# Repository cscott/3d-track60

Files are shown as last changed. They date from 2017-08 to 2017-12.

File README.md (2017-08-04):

# Track for wooden trains (Brio, Lillabo, Thomas, etc) using 60° system

Thing tracker at:
https://cscott.github.io/thing-tracker/#/thing/4b2b1909-8ae7-4448-a28f-22e28d4b5b43

## Description

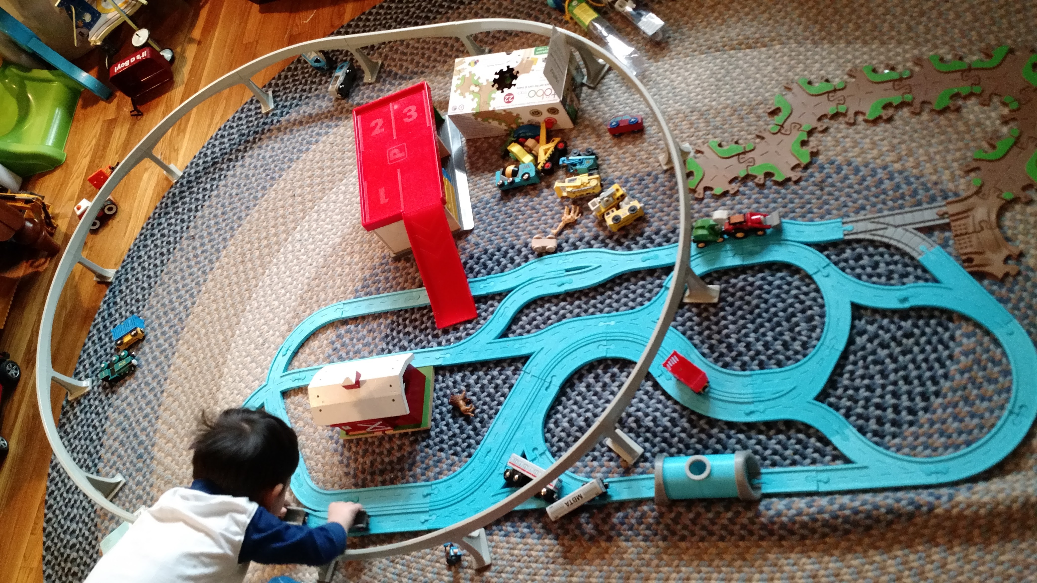
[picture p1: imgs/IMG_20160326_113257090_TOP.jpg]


These files contain a set of wooden-train-compatible track pieces in
the [sixty-degree system described by Dave
Barber](http://tamivox.org/dave/train/index60.html).  Unlike the
hodgepodge of pieces in the standard Brio/Thomas/Ikea/etc sets, track
assembled using these pieces will always go together and fit
perfectly.  No more frustration for you or your kids when your loops
don't *quite* close up.  No more [flexible
track](https://www.thingiverse.com/thing:661462) kludges.

In addition, I've made adapter pieces for many popular accessories,
such as those from the
[Ertl Hometown Roadway](http://magicref.tripod.com/trains/trainhistory2.htm),
so that they fit into the 60-degree system.

#### Some discussion of size

Dave Barber suggests a base radius for the system of 200mm.  The core
hexagon will then have a diameter of 267mm and straights will be 231mm
long.

I have instead chosen a base radius of 154mm, which makes 7 hex cells
arranged flat-to-flat measure 49 inches.  That works well with a
[wTrak]-like system with 48" tables and 1" gaps between them (filled
with leg assemblies).  Our straights are about 7" long.

For comparison, according to
[woodenrailway.info](http://www.woodenrailway.info/track/trackguide.html)
the standard Brio "E" curve has a centerline radius of 202mm
and the tighter Brio "E1" curve has a centerline radius of 110mm.
Typical Brio straights are 4.5", 5.5", and 8.5".  Our 154mm curves
and 7" straights fit reasonably well into this family.

For riser heights, although the Brio standard is 64mm, some other sets
have 62mm risers.  We've split the difference in making levels separated
by 63mm.  This should be easily interoperable with existing pieces using
either the 62mm or 64mm heights.

We like the ["clickity-clack track that Learning Curve abandoned years ago"](http://wtrak.org/tracks.htm) so our rail pieces contain grooves for the ties
in order to make that audible clack as trains are rolled over it.
Most of our pieces have road on one side and rail on the other, so you
can play with cars or trains or both.

<br clear="both" />

## Related

* Dave Barber's [Observations on Track for Toy Trains](http://tamivox.org/dave/train/)

## License

These designs are licensed under the [GPLv2+].

[wTrak]: http://wtrak.org/
[GPLv2+]: https://spdx.org/licenses/GPL-2.0+.html

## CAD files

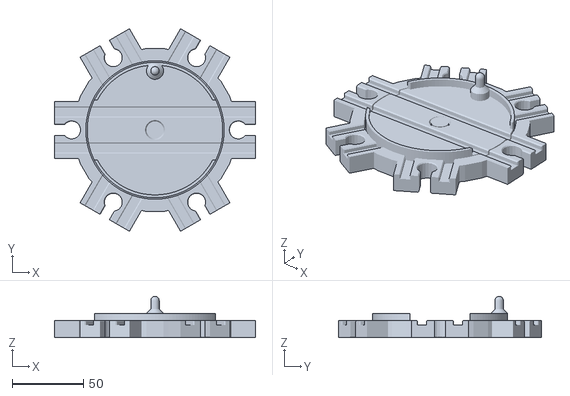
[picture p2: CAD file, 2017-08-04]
roundabout-stl/roundabout-6-assembled.stl
141.0 x 142.1 x 29.0

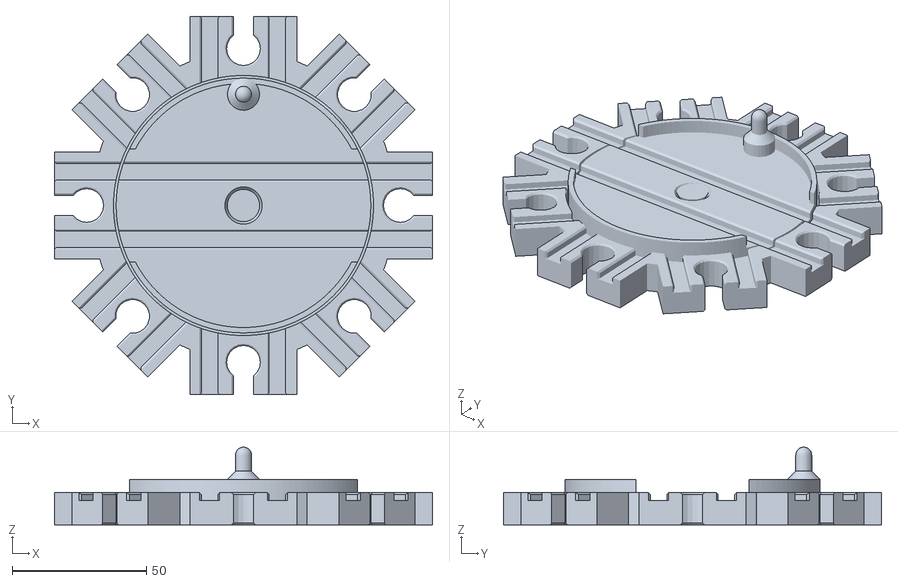
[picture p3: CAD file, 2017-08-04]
roundabout-stl/roundabout-8-assembled.stl
141.0 x 141.0 x 29.0

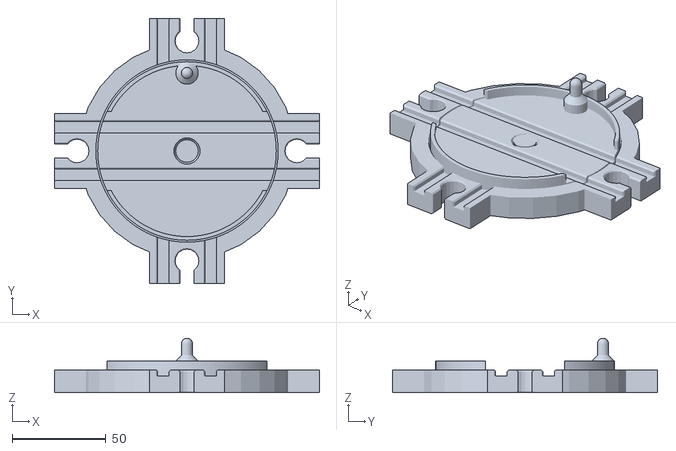
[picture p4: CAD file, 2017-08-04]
roundabout-stl/roundabout-4-assembled.stl
141.0 x 141.0 x 29.0

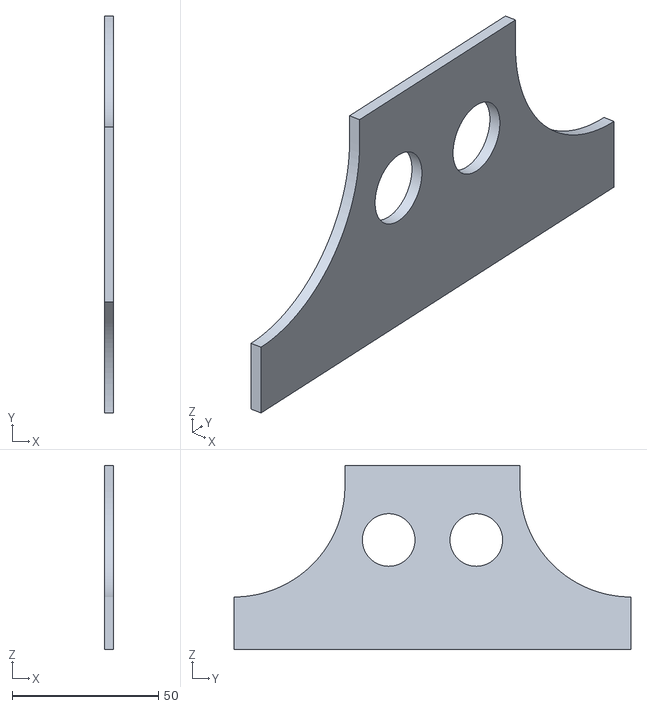
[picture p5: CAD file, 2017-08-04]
track60-boat-stl/track60-boat-side-left.stl
3.00 x 135.8 x 63.0

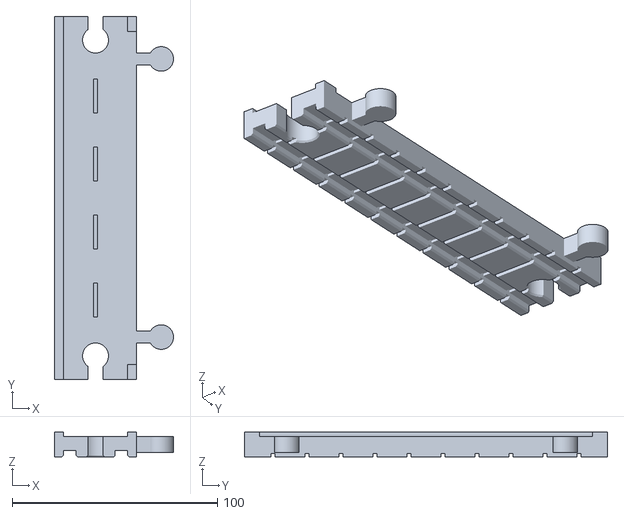
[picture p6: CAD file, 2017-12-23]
track60-stl/track60-pez.stl
58.0 x 176.8 x 12.0

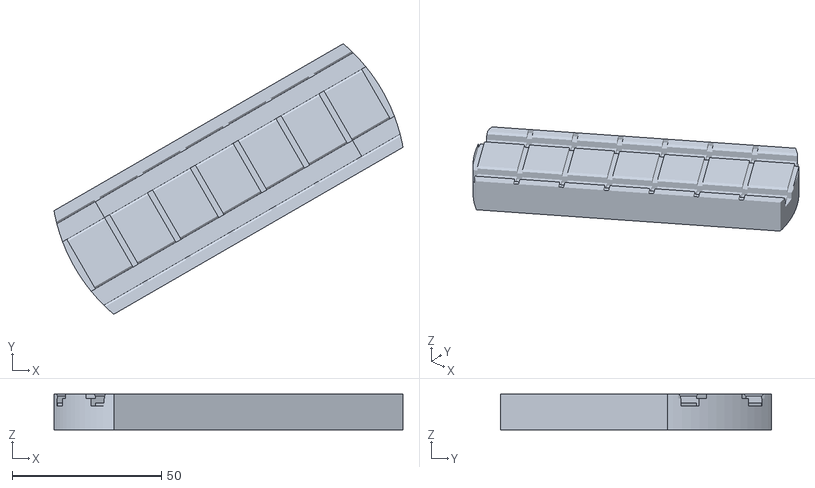
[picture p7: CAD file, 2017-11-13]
track60-swing-bridge-stl/track60-swing-bridge-swing-rail-rail-AT.stl
116.8 x 90.5 x 12.0

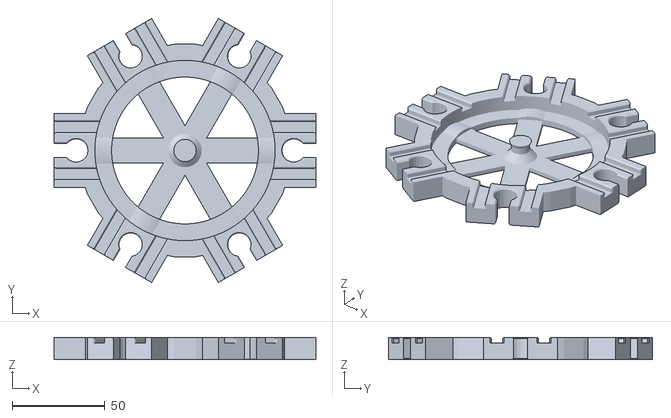
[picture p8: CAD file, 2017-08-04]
roundabout-stl/roundabout-6-outer.stl
141.0 x 142.1 x 12.0

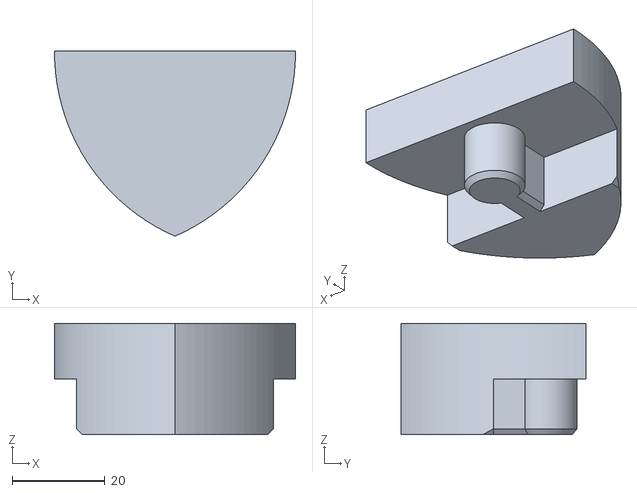
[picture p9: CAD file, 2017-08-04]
track60-boat-stl/track60-boat-end.stl
52.0 x 40.0 x 24.0

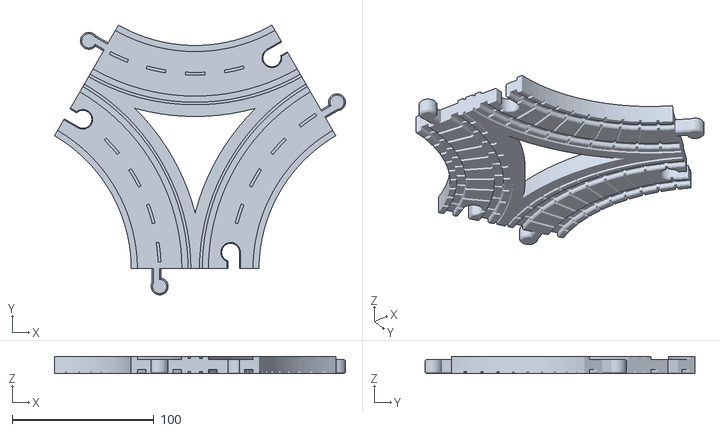
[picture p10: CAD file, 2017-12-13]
track60-stl/track60-name-pA++pA++pA.stl
205.0 x 190.1 x 12.0

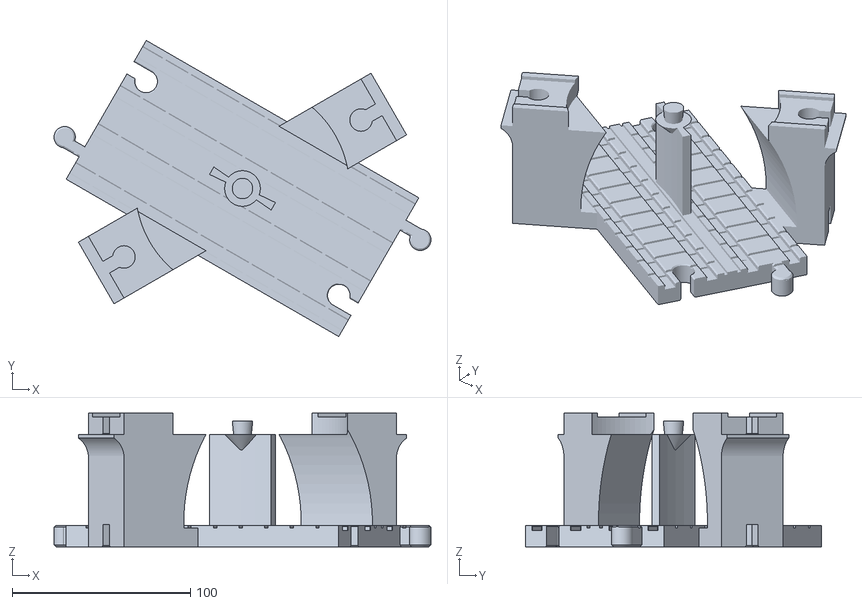
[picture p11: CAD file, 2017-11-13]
track60-swing-bridge-stl/track60-swing-bridge-base-rail-road-AT.stl
211.8 x 166.4 x 75.0

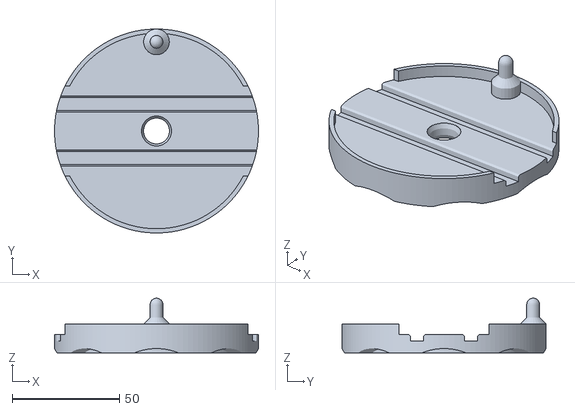
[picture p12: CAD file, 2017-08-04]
roundabout-stl/roundabout-8-inner.stl
95.0 x 95.0 x 25.5

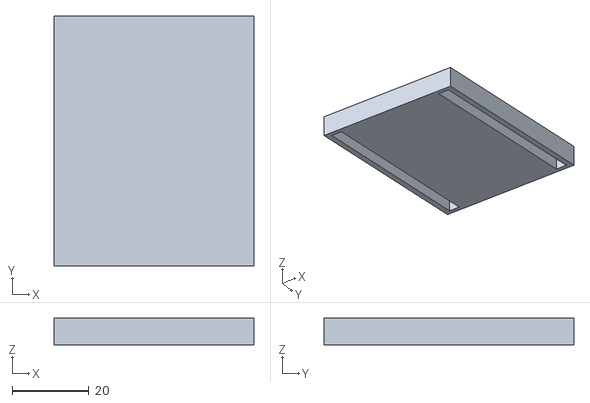
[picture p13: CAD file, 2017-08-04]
track60-boat-stl/track60-boat-top.stl
52.0 x 65.0 x 7.00

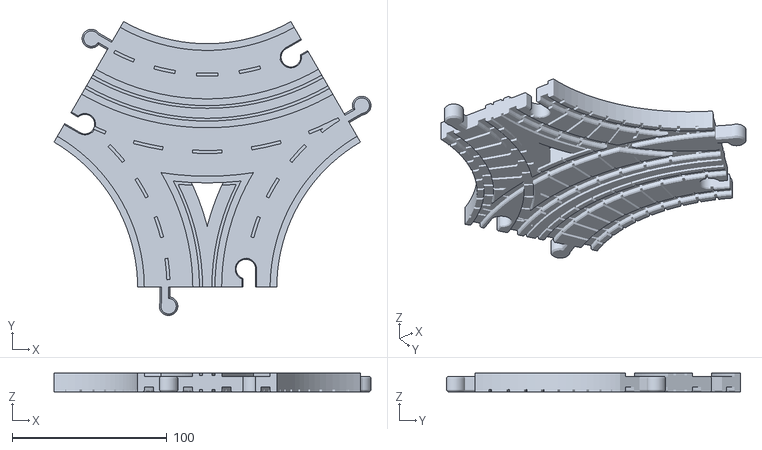
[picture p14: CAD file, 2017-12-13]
track60-stl/track60-name-pA+bs+pA.stl
205.0 x 190.1 x 12.0

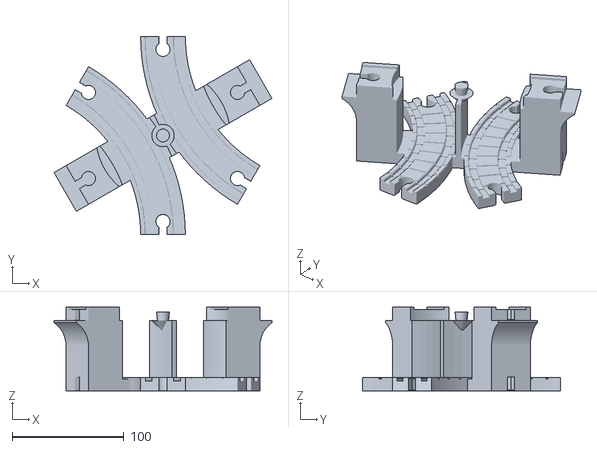
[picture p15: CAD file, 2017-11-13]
track60-swing-bridge-stl/track60-swing-bridge-base-rail-road-ES.stl
194.8 x 176.8 x 75.0

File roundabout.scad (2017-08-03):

/* Roundabout for brio-compatible trains */

/* [Global] */

// This design is composed of a number of separate printable parts:
part = "6_assembled"; // [4_assembled:Four-way roundabout (assembly),4_inner:Four-way roundabout (inner piece),4_outer:Four-way roundabout (outer piece),6_assembled:Six-way roundabout (assembly),6_inner:Six-way roundabout (inner piece),6_outer:Six-way roundabout (outer piece),8_assembled:Eight-way roundabout (assembly),8_inner:Eight-way roundabout (inner piece),8_outer:Eight-way roundabout (outer piece)]

/* [Hidden] */
use <trains/tracklib.scad>;

roundabout_demo(part);

// Sample instantiations
module roundabout_demo(part="6_assembled", size="medium") {
  if (part=="4_assembled") {
    roundabout(num=2, which="both", size=size); // show both inner and outer for a 4-way roundabout
  } else if (part=="4_inner") {
    roundabout(num=2, which="inner", size=size); // inner for 4-way
  } else if (part=="4_outer") {
    roundabout(num=2, which="outer", size=size); // 4-way outer piece
  } else if (part=="6_assembled") {
    roundabout(num=3, which="both", size=size); // show both inner and outer for a 6-way roundabout
  } else if (part=="6_inner") {
    roundabout(num=3, which="inner", size=size); // inner for 6-way
  } else if (part=="6_outer") {
    roundabout(num=3, which="outer", size=size); // 6-way outer piece
  } else if (part=="8_assembled") {
    roundabout(num=4, which="both", size=size); // show both inner and outer for 8-way
  } else if (part=="8_inner") {
    roundabout(num=4, which="inner", size=size); // 8-way inner piece
  } else if (part=="8_outer") {
    roundabout(num=4, which="outer", size=size); // 8-way outer piece
  }
}

// "small" size can only be used for 4 or 6 way.
// "medium" is the largest that can fit on a 6"x6" printer.
module roundabout(size="medium", num=3, which="both") {
  inner_piece = (which=="inner") || (which=="both");
  outer_piece = (which=="outer") || (which=="both");
  if (size=="small") {
    roundabout_custom(inner=80, outer=53.5,
                      num=num, inner_piece=inner_piece, outer_piece=outer_piece);
  } else if (size=="large") {
    roundabout_custom(inner=152, outer=53.5,
                      num=num, inner_piece=inner_piece, outer_piece=outer_piece);
  } else { // "medium" size
    roundabout_custom(inner=95, outer=46,
                      num=num, inner_piece=inner_piece, outer_piece=outer_piece);
  }
}

// inner is "roundabout" diameter.
// outer is the additional length of the
// 'stubs' reaching out from the roundabout
module roundabout_custom(inner=95, outer=46, clearance=1, num=3, snap_fit=true,
                  inner_piece=true, outer_piece=true, rails=true,
                  hub_height=wood_height(), inner_num=1,
                  spin_knob=0, full_custom=false) {
  // Dimensions
  total = inner + outer;
  base_height = 2.5;
  outer_rim = 10;
  base_rim = 8;
  snap_fit_height = 2;
  hub_diam = 10;
  hub_ramp = min(4, max(0,
                 hub_height - base_height - (snap_fit?snap_fit_height:0) - 1));
  strut_width = num < 4 ? wood_width()/3 : wood_width()/4;
  guard_height = 5;
  guard_width = 2;
  knob_height = 14;
  knob_diam = 6;
  res = 120; // rotating pieces resolution
  knob_res = 25; // knob resolution

  // Outer piece
  if (outer_piece) {
    difference() {
      // Start with `num` tracks and a cylinder around them, then
      // carve away stuff.
      union() {
        if (full_custom) {
          children(0);
        } else {
          for ( i = [0:num-1] ) {
            rotate( [0, 0, i * 180 / num ]) {
              wood_track_centered( total, rails=false );
            }
          }
        }
        cylinder(h=wood_height(), d=inner + outer_rim*2);
      }
      // Carve away the rails, and female connectors
      if (full_custom) {
        children(1);
      } else {
        for ( i = [0:num-1] ) {
          rotate( [0, 0, i * 180 / num ]) {
            if (rails) wood_rails_centered( total );
            translate([-total/2,0,0])
              wood_cutout();
            translate([total/2,0,0]) rotate([0,0,180])
              wood_cutout();
          }
        }
      }
      // Carve away the central cutout (less the hub)
      difference() {
        union() {
          translate([0, 0, base_height + clearance])
            cylinder(h=wood_height(), d=inner + (clearance*2), $fn=res);
          translate([0, 0, base_height])
            cylinder(h=wood_height(), d=inner - (base_rim*2), $fn=res);
        }
        translate([0,0,-base_height])
          cylinder(h=hub_height + base_height, d=hub_diam, $fn=res);
        translate([0,0,base_height])
          cylinder(h=hub_ramp, d1=hub_diam + hub_ramp*2, d2=hub_diam, $fn=res);
      }
      // Carve away the openings to the ground
      // formed by adding back `cube` shaped struts.
      translate([0,0,-clearance]) difference() {
        // central cutout minus the base rim
        cylinder(h=wood_height() + clearance*2,
                 d=inner - base_rim*2, $fn=res);
        translate([0, 0, -clearance]) {
          // minus the hub (and a base_rim sized rim around it)
          cylinder(h=( wood_height() + clearance*4 ),
                   d=( hub_diam + (hub_ramp*2) + base_rim) );
          // struts at each of the track locations
          for ( i = [0:num-1] ) {
            rotate( [0, 0, i * 180 / num ]) {
              cube(size=[inner, strut_width, 2*(wood_height() + clearance*4)],
                   center=true);
            }
          }
        }
      }
    }
    // add an extra "snap fit" widening of central shaft
    if ( snap_fit ) {
      translate([0, 0, hub_height - snap_fit_height])
        cylinder(h=snap_fit_height, d1=hub_diam, d2=hub_diam + clearance*2,
                 $fn=res);
    }
    // Detents
    roundabout_detents(num=num, base_height=base_height, base_rim=base_rim,
                       inner=inner, clearance=clearance, res=res,
                       inner_piece=false);
  }

  // Inner rotating piece
  if (inner_piece) {
    // Put this piece flat on the xy plane if we're rendering it by itself.
    translate([0, 0, outer_piece||!rails ? 0 : -(base_height + clearance)]) {
      // Main cylinder body, minus rails and hub clearances
      difference() {
        // Main body
        translate([0, 0, base_height + clearance])
          cylinder(h=wood_height() - (base_height + clearance),
                   d=inner, $fn=res);
        // Rails down the center
        if (full_custom) {
          children(3);
        } else if (rails) {
          wood_rails_centered(inner);
        }
        // Central hub
        cylinder(h=hub_height + clearance,
                 d=hub_diam + clearance*2, $fn=res);
        // Hub ramp (start low @ base_height to ensure we punch through)
        translate([0, 0, base_height])
          cylinder(h=hub_ramp + clearance*sqrt(2),
                   d1=hub_diam + hub_ramp*2 + clearance*sqrt(2)*2,
                   d2=hub_diam, $fn=res);
        // Snap fit hub (add extra clearance/10 height to ensure we punch thru)
        if (snap_fit) {
          translate([0, 0, hub_height - snap_fit_height]) {
            cylinder(h=snap_fit_height,
                     d1=hub_diam + clearance*2,
                     d2=hub_diam + clearance*4, $fn=res);
            translate([0,0,snap_fit_height-clearance/10])
              cylinder(h=clearance+clearance/10,
                       d=hub_diam + clearance*4, $fn=res);
          }
        }
        // Detents
        roundabout_detents(num=num, base_height=base_height, base_rim=base_rim,
                           inner=inner, clearance=clearance, res=res,
                           inner_piece=true);
      }
      // add a bit of "guard rail"
      translate([0, 0, wood_height() - clearance]) {
        difference() {
          translate([0, 0, clearance/2]) // just ensure we sink into top
            cylinder(h=guard_height + clearance/2, d=inner, $fn=res);
          cylinder(h=guard_height + clearance*2, d=inner - guard_width*2, $fn=res);
          // protect the track
          if (full_custom) {
            children(2);
          } else {
            for ( i = [0:1:inner_num-1] ) rotate( [0, 0, i * 180 / num ])
              cube([inner + clearance,
                    wood_width() + clearance*2,
                    2*(guard_height + clearance*2)], center=true);
          }
        }
      }
      // now add knob
      rotate([0,0,spin_knob])
      translate([0, inner/2 - knob_diam, wood_height() - clearance]) {
        // shaft
        cylinder(h=knob_height + clearance, d=knob_diam, $fn=knob_res);
        cylinder(h=guard_height + clearance, d=knob_diam*2, $fn=knob_res);
        // ramp
        translate([0, 0, guard_height+clearance])
          cylinder(h=knob_diam/2, d1=knob_diam*2, d2=knob_diam, $fn=knob_res);
        // round top
        translate([0, 0, knob_height + clearance])
          sphere(d=knob_diam, $fn=knob_res);
      }
    }
  }
}
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

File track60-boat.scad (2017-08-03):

/* Ferry boat for 60-degree track system. */

/* [Global] */
part = "all"; // [bottom,side-left,side-right,top,end]

/* [Hidden] */
use <track60.scad>
use <trains/tracklib.scad>;
use <common/arch.scad>;
basic_radius = 154;
$fn = 120;

function boat_top_height() = riser_height();
function boat_top_length() = 65;
function boat_top_overhang() = 2.5;
function boat_end_height() = wood_height()*2;
function boat_end_overlap() = wood_width()/2;
function boat_end_depth() = 20;
function boat_side_width() = 3;
function boat_width() = wood_width() + 2*(boat_side_width() + 2*boat_side_clearance() + 2);
function boat_clearance() = 1;
function boat_side_clearance() = 0.5;
function boat_side_slot_depth() = wood_height()/2;
function boat_window_diam() = 18;

track60_boat_part(part=part);

module track60_boat_part(radius=basic_radius, part="all") {
  if (part=="all") {
    track60_boat_part(radius, "bottom");
    for (i=[0,180]) rotate([0,0,i])
      track60_boat_part(radius, "end");
    track60_boat_part(radius, "side-left");
    track60_boat_part(radius, "side-right");
    track60_boat_part(radius, "top");
  } else if (part=="bottom") {
    track60_boat_bottom(radius);
  } else if (part=="end") {
    track60_boat_end(radius);
  } else if (part=="side-left") {
    track60_boat_side(radius);
  } else if (part=="side-right") {
    scale([-1,1,1]) track60_boat_part(radius, "side-left");
  } else if (part=="top") {
    track60_boat_top(radius);
  }
}

module track60_boat_top(radius=basic_radius) {
  top_thick = boat_side_slot_depth() + 1;
  difference() {
    translate([0,0,boat_top_height() + top_thick/2])
      cube([boat_width(), boat_top_length(), top_thick], center=true);
    // slots for sides
    for (i=[1,-1]) scale([i,1,1])
      translate([wood_width()/2 + boat_side_clearance() + boat_side_width()/2,
                 0,
                 boat_top_height()])
        cube([boat_side_width() + 2*boat_side_clearance(),
              boat_top_length() - 2*(boat_top_overhang()-boat_clearance()),
              2*(boat_side_slot_depth()+boat_side_clearance())], center=true);
  }
}

module track60_boat_side(radius=basic_radius) {
  total_height = boat_top_height() - wood_height() + 2*boat_side_slot_depth();
  cutoutr = boat_top_height() + boat_side_slot_depth() - boat_end_height();

  window_diam = boat_window_diam();
  side_width = boat_side_width();
  side_length = straight_length(radius)
    - 2*(boat_end_overlap() + boat_clearance());
  bottom = wood_height() - boat_side_slot_depth();
  short_top_length = boat_top_length() - 2*boat_top_overhang();
  cutoutr2 = min(cutoutr, (side_length - short_top_length)/2);
  window_cheat = 2;

  translate([wood_width()/2 + boat_side_clearance(),0,0]) difference() {
    union() {
      translate([0, -side_length/2, bottom])
        cube([side_width, side_length, boat_end_height() - bottom]);
      translate([0, -short_top_length/2, bottom])
        cube([side_width, short_top_length, total_height]);

      translate([0, -short_top_length/2 - cutoutr2, boat_end_height()])
        cube([side_width, short_top_length + 2*cutoutr2, cutoutr2]);
    }
    for(i=[1,-1]) scale([1,i,1]) {
      // Rounded corners
      translate([0,
                 short_top_length/2 + cutoutr2,
                 boat_end_height() + cutoutr2])
        rotate([0,90,0])
        cylinder(r=cutoutr2, h=3*side_width, center=true);
      // Windows
      translate([0,
                 ((short_top_length - 2*window_diam)/3 + window_diam)/2 +
                 window_cheat,
                 boat_end_height() +
                 (boat_top_height() - boat_end_height())/2])
        rotate([0,90,0])
        cylinder(d=window_diam, h=3*side_width, center=true);
    }
  }
}

module track60_boat_bottom_chamfer(radius=basic_radius) {
  for(i=[1,-1]) scale([i,1,1])
    translate([boat_width()/2, 0, 0])
    rotate([0,45,0])
    cube([wood_height()/sqrt(2), straight_length(radius)+2*boat_end_depth(),
          2*wood_height()],
         center=true);
}

module track60_boat_bottom(radius=basic_radius) {
  intersection() {
  difference() {
    translate([0,0,wood_height()/2])
      cube([boat_width(), straight_length(radius), wood_height()], center=true);
    straight60(radius, "rail-blank", "hole");
    straight60(radius, "rail-blank", "connector");
    // chamfer on bottom
    track60_boat_bottom_chamfer(radius);
    // slots for sides
    for (i=[1,-1]) scale([i,1,1])
      translate([wood_width()/2 + boat_side_clearance() + boat_side_width()/2,
                 0, wood_height()])
        cube([boat_side_width() + 2*boat_side_clearance(),
              straight_length(radius) - 2*boat_end_overlap(),
              2*(boat_side_slot_depth() + boat_side_clearance())], center=true);
  }
  union() {
    translate([0,0,wood_height()])
    cube([boat_width(),
          straight_length(radius)-2*boat_end_overlap(),
          3*wood_height()], center=true);
    for (i=[1,-1]) scale([1,i,1]) track60_boat_end_arch(radius);
  }
  }
}

module track60_boat_end_arch(radius=basic_radius) {
  translate([0,-straight_length(radius/2)+boat_end_overlap(),0]) scale([1,-1,1])
    arch2(width=boat_width(), height=boat_end_overlap() + boat_end_depth(),
          thick=2*boat_end_height() + boat_clearance(), ratio=2.5, center=true);
}

module track60_boat_end(radius=basic_radius) {
  intersection() {
    union() {
      translate([0,-straight_length(radius)/2,0])
        scale([1,1,1.2]) rotate([0,0,90]) wood_plug();
      difference() {
        translate([-boat_width()/2,
                   -straight_length(radius)/2 - boat_end_depth(),
                   0])
          cube([boat_width(), boat_end_overlap() + boat_end_depth(), boat_end_height()]);
        cube([boat_width()+2*boat_clearance(),
              straight_length(radius),
              2*wood_height()], center=true);
        track60_boat_bottom_chamfer(radius);
      }
    }
    track60_boat_end_arch(radius);
  }
}

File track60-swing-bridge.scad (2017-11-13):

/* Swinging draw bridge */

/* [Global] */

// Which part.
part = "base"; // [base,swing]

// What surface to put on the lower and upper levels (respectively)
surface = "rail-road"; // [road-road,rail-rail,road-rail,rail-road]

// What style (gantlet or straight crossing)
style = "ES"; // [ES, AT]

/* [Hidden] */
use <track60.scad>;
use <trains/tracklib.scad>;
use <common/arch.scad>
use <common/strutil.scad>

basic_radius = track60_basic_radius();
$fn=120;

function swing_margin() = 8;
function swing_center_gap() = 2.5;
function swing_pivot_radius() = 10;
function swing_radius(radius) = (straight_length(radius) - radius) +
  sqrt(2)*(wood_width()/2) + swing_margin();

function base_surface(surface) = str(split(surface, "-")[0], "-blank");
function swing_surface(surface)= str(split(surface, "-")[1], "-blank");
function flip_surface(surface) = str(split(surface, "-")[1], "-", split(surface, "-")[0]);

track60_swing_bridge(part=part, surface=surface, style=style);

module track60_swing_bridge(radius=basic_radius, part="all", surface="rail-rail", style="ES") {
  if (part == "all") {
    track60_swing_bridge(radius, "base", surface, style);
    track60_swing_bridge(radius, "swing", surface, style);
  } else if (part == "base") {
    swing_bridge_base(radius, surface, style);
  } else if (part == "swing") {
    swing_bridge_swing(radius, surface);
  }
}

module swing_bridge_base(radius=basic_radius, surface="rail-rail", style="ES") {
  type_is_gantlet = (style == "ES");
  dogbone_clearance = 0.5;
  // basic gantlet
  if (type_is_gantlet) {
    shortname60(radius, "ES", base_surface(surface));
  } else {
    bsurface = base_surface(surface);
    if (bsurface == "road-blank") {
      shortname60(radius, "at", bsurface);
    } else {
      translate([0,0,wood_height()/2]) rotate([0,180,0]) translate([0,0,-wood_height()/2])
        shortname60(radius, "av", flip_surface(bsurface));
    }
  }
  // ends of swing
  difference() {
    union() {
      translate([0,0,riser_height()])
        shortname60(radius, "AV", swing_surface(surface));
      translate([0,0,riser_height()/2]) rotate([0,0,-60])
        cube([wood_width(),
              straight_length(radius) - 2*dogbone_clearance,
              riser_height()],
          center=true);
    }
    // cut out gantlet arc so swing part can rest of protrusion.
    if (type_is_gantlet) {
      difference() {
        translate([0,0,wood_height()/2 + wood_well_height()/2])
          cylinder(r=swing_radius(radius), h=2*riser_height());
        for (i=[1,-1]) rotate([0,0,-60]) scale([1,i,1])
          translate([0,-straight_length(radius),0])
          cylinder(r=radius - wood_width()/2 - swing_margin(),
                   h=riser_height());
      }
    } else {
      translate([0,0,riser_height()])
        cylinder(r=swing_radius(radius), h=riser_height());
       rotate([0,0,60])
         translate([0,0,wood_height()/2 + wood_well_height()/2])
         rotate([90,0,0])
         arch2(2*wood_width() + double_gutter() + 2*swing_margin(),
               1.5*riser_height(), 2*radius, center=true);
    }
    // clear roadway
    if (type_is_gantlet) {
      for (i=[0,180]) rotate([0,0,i])
        translate([-radius,-straight_length(radius)/2,-1])
          ring(radius, 60, wood_height() + 2, wood_width() - 0.1);
    } else {
      rotate([0,0,60])
        cube([2*wood_width() + double_gutter() - 0.1,
              2*radius, 2*wood_height() + 2], center=true);
    }
    // cutout dogbone at bottom
    for (i=[1,-1]) rotate([0,0,-60])
      scale([1,i,1]) translate([0,straight_length(radius)/2,0]) intersection() {
      clearance=0.5; epsilon=.05;
      scale([1,1,(wood_height()+bevel()+clearance)/wood_height()])
        rotate([0,0,-90]) wood_cutout();
      translate([-wood_width()/2, -radius, -epsilon])
        cube([wood_width(), 2*radius, wood_height() + clearance + epsilon]);
    }
  }
  // center support pillar
  rotate([0,0,type_is_gantlet ? -60 : -30]) difference() {
    translate([0,0,riser_height()/2])
      cube([wood_width(), 2*(straight_length(radius) - radius), riser_height()],
         center=true);
    difference() {
    for (i=[1,-1]) scale([1,i,1]) translate([0,-straight_length(radius), 0])
      cylinder(r=radius + wood_width()/2 + swing_center_gap(),
               h=3*riser_height(), center=true);
    translate([0,0,riser_height() - swing_pivot_radius()])
      cylinder(r1=0, r2=swing_pivot_radius(), h=swing_pivot_radius());
    }
  }
  // center pivot
  swing_bridge_pivot(clear=false);
  // extra support for raised track
  ledge = wood_plug_radius() * (type_is_gantlet ? 2 : 1);
  ledge_thick = 2; // thickness before arch cutout starts
  for (i=[0,180]) rotate([0,0,-60 + i]) difference() {
    epsilon = 0.05;
    translate([-wood_width()/2,
               straight_length(radius)/2 - dogbone_clearance - epsilon,
               wood_height()])
      cube([wood_width(),
            ledge + dogbone_clearance + epsilon,
            riser_height() - wood_height()]);
    translate([0, straight_length(radius)/2 + ledge, 0])
      rotate([90,0,90])
        arch2(2*(ledge + dogbone_clearance) + 3*epsilon,
              riser_height() - ledge_thick,
              wood_width() + epsilon, center=true);
  }
}

module swing_bridge_pivot(clear=false) {
  clearance = 0.75;
  pivot_height = wood_well_height() - (0.2*3) - clearance;
  pivot_r = 5;
  epsilon = 0.01;
  translate([0,0,riser_height() - epsilon])
    cylinder(r1 = pivot_r + (clear?clearance:0),
             r2 = pivot_r + clearance + (clear?clearance:0),
             h = pivot_height + epsilon);
  if (clear)
    translate([0,0,riser_height() + pivot_height - epsilon])
      cylinder(r = pivot_r + 2*clearance, h = clearance + epsilon);
}

module swing_bridge_swing(radius=basic_radius, surface="rail-rail") {
  clearance = 0.75;
  intersection() {
    translate([0,0,riser_height()])
      shortname60(radius, "AV", swing_surface(surface));
    difference() {
      cylinder(r=swing_radius(radius)-clearance, h=2*riser_height());
      swing_bridge_pivot(clear=true);
    }
  }
}

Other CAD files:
roundabout-stl/roundabout-8-outer.stl
track60-boat-stl/track60-boat-side-right.stl
track60-stl/track60-name-BS==14.stl
track60-swing-bridge-stl/track60-swing-bridge-swing-road-road-AT.stl
track60.scad
roundabout-stl/roundabout-4-inner.stl
roundabout-stl/roundabout-4-outer.stl
roundabout-stl/roundabout-6-inner.stl
track60-boat-stl/track60-boat-bottom.stl
track60-stl/track60-barn-dogbone.stl
track60-stl/track60-barn.stl
track60-stl/track60-big-curved-slope.stl
track60-stl/track60-big-slope.stl
track60-stl/track60-buffer-rail.stl
track60-stl/track60-buffer-road.stl
track60-stl/track60-carwash.stl
track60-stl/track60-crossing1.stl
track60-stl/track60-crossing10.stl
track60-stl/track60-crossing2.stl
track60-stl/track60-crossing3.stl
track60-stl/track60-crossing4.stl
track60-stl/track60-crossing5.stl
track60-stl/track60-crossing6.stl
track60-stl/track60-crossing7-left.stl
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

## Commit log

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2015-03-03 Improvements to roundabout after first printing.
    [roundabout.scad]
2015-03-28 roundabout: add new roundabout-render.py script.
    [roundabout.scad]
2015-03-31 roundabout: shrink 8-way to fit on printrbot bed.
    [roundabout.scad]
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2015-04-10 roundabout: make detents more gentle.
    [roundabout.scad]
2015-04-14 roundabout: tweak default sizes.
    [roundabout.scad]
2016-03-14 Fix roundabout detent.
    [roundabout.scad]
2016-03-14 wooden train track pieces on 60 degree system.
    Thanks to Dave Barber for the math & analysis.
    [track60.scad]
2016-03-14 Add fancy rails to track60 roundabout.
    [roundabout.scad, track60.scad]
2016-03-14 increase base radius to 170mm; make ties and stripes line up better.
    [track60.scad]
2016-03-15 base radius is now 154mm; add double-track pieces.
    [track60.scad]
2016-03-15 trim length of pieces to loosen the fit of the connectors.
    [track60.scad]
2016-03-16 add two more double-track switches.
    [track60.scad]
2016-03-16 renumber switches and add direction parameter
    [track60.scad]
2016-03-16 improve ties on switch7
    [track60.scad]
2016-03-16 add a few more double-to-single switches.
    [track60.scad]
2016-03-17 Make `dir`, `gutter`, and `trim_ties` parameters consistent.
    [track60.scad]
2016-03-17 add a bunch of new double-track switches and crossings.
    [track60.scad]
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2016-03-20 Tweak road width and height.
    track width and spacing in tracklib has also been tweaked slightly.
    [track60.scad]
2016-03-24 ensure loose connector trim of double-wide tracks.
    [track60.scad]
2016-03-30 add half double, slope, and "building" pieces.
    [track60.scad]
2016-04-02 fix regression in bottom-side rails.
    [track60.scad]
2016-04-03 add piece to adapt the Texaco Carwash to the 60-degree system.
    [track60.scad]
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2016-07-14 add firehouse adapter piece.
    [track60.scad]
2017-03-08 add crossing4 variant; tweak for shorter hub.
    [roundabout.scad, track60.scad]
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2017-03-11 refactor part name parsing; add roundabout w/ roads.
    [track60.scad]
2017-03-11 separate dogbone from barn connector piece.
    [track60.scad]
2017-03-11 switch to asymmetric connector for double track; up rise to 64mm.
    [track60.scad]
2017-03-13 add adapter pieces for existing double track.
    [track60.scad]
2017-03-13 fixes for adapter shim.
    [track60.scad]
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2017-03-15 refactor so that top and bottom surfaces are individually specified.
    This allows explicitly asking for "blank" surfaces, and ensures that
    double-tracked pieces are blank on sides where the double-track connector
    would be improperly mirrored. In the future I might add "fast" surfaces,
    which carve out deep 45-degree channels on the unused side to reduce the
    volume of the piece and allow faster printing.
    [track60.scad]
2017-03-15 update comment about blanking double pieces.
    [track60.scad]
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2017-03-15 attempt to fix "not a valid 2-manifold" warnings for switch6.
    [track60.scad]
2017-03-16 add riser variant w/ integral dogbone; decrease rise to 63mm.
    [track60.scad]
2017-03-16 tweak slope to sit flat on riser.
    [track60.scad]
2017-03-16 use dogbone variant of riser by default.
    [track60.scad]
2017-03-16 add adapter for Hometown Roadway Recycling center.
    [track60.scad]
2017-03-17 add two grade crossings.
    [track60.scad]
2017-03-17 rework gutter for recycling adapter.
    [track60.scad]
2017-03-17 fix stripes and ties for non-standard curve radii.
    [track60.scad]
2017-03-17 add gutter to thomas grade crossing adapter.
    [track60.scad]
2017-03-17 variant of crossing3 where road crosses rail.
    [track60.scad]
2017-03-17 fix position of side cutouts on recycling adapter.
    [track60.scad]
2017-03-18 add variant of recycling adapter w/ split surfaces.
    [track60.scad]
2017-03-19 add double-track version of ramp/buffer.
    [track60.scad]
2017-03-19 add switch #17, a variant of crossing #1.
    [track60.scad]
2017-03-20 begin to support Dave Barber's nomenclature system.
    [track60.scad]
2017-03-22 purge gutter boolean; port crossings to new shortname module.
    [track60.scad]
2017-03-22 port switches and misc to new shortname module.
    [track60.scad]
2017-03-22 add 'just_curve' sway variants.
    [track60.scad]
2017-03-22 mirror connector on double-track rail buffers/ramps.
    [track60.scad]
2017-03-22 no gutter on blank sides.
    [track60.scad]
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2017-03-24 allow two-part surface suffixes, like '-blank-blank'.
    [track60.scad]
2017-03-24 refactor roundabout into separate module.
    [track60.scad]
2017-03-26 initial attempt at double-track roundabout.
    The dimensions don't actually work out -- it would have to be at
    least 25% larger (preferably 50%) and occupy multiple hexes.
    Then the outer ring wouldn't actually fit on my 3d printer and
    I'd have to segment it somehow...
    [roundabout.scad, track60.scad]
2017-03-26 add gas station and post office adapter pieces.
    [track60.scad]
2017-03-26 add lift cutout for gas station; fix improper road/rail trim.
    [track60.scad]
2017-03-26 hacky double-to-2x-single converter for a bridge I have.
    [track60.scad]
2017-03-29 add new single-to-double switch #1 parts.
    [track60.scad]
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2017-03-29 shorten postoffice, round corners, and trim to allow straight.
    [track60.scad]
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2017-07-23 add sloping curve piece w/ an arched base.
    [track60.scad]
2017-07-23 bug fix for named pieces which are blank on one side.
    [track60.scad]
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2017-08-03 Fix 'undefined dir' warning.
    [track60.scad]
2017-08-04 Fix warnings and errors from render script.
    [track60-swing-bridge.scad, track60.scad]
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2017-11-12 Add adapter pieces for the Pez Factory / First Response station.
    [track60-pez.stl, track60-pez2.stl, track60.scad]
2017-11-13 Add new style of swing bridge, and add support for raised track.
    [track60-swing-bridge-base-rail-rail-AT.stl, track60-swing-bridge-base-rail-rail-ES.stl, track60-swing-bridge-base-rail-road-AT.stl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]
2017-11-13 Fix support for raised track.
    [track60-swing-bridge-base-rail-rail-AT.stl, track60-swing-bridge-base-rail-rail-ES.stl, track60-swing-bridge-base-rail-road-AT.stl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]
2017-12-11 Fix single buffer/ramp.
    [track60-buffer-rail.stl, track60-buffer-road.stl, track60-ramp-rail.stl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]
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2017-12-13 Add squeeze hack for dbl_roundhouse to fit the piece on my printer bed.
    [track60.scad]
2017-12-13 Fix double connector on dbl_roundabout*-rail.
    [track60.scad]
2017-12-13 Add rotation operator to shortname module.
    [track60.scad]
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2017-12-13 Add "left only" and "right only" double-track straights and curves.
    [track60-name-pA++pA++pA.stl, track60-name-pA+bs+pA.stl, track60.scad]
2017-12-23 Turn off "squeeze mode" for outer dbl-roundabout by default.
    [track60.scad]
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
